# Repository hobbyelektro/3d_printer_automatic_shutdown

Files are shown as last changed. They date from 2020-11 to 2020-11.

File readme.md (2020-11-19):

# Automatic 3D printer shutdown



Documentation
--------------------
https://www.hobbyelektro.eu/automaticke-vypnuti-3d-tiskarny/

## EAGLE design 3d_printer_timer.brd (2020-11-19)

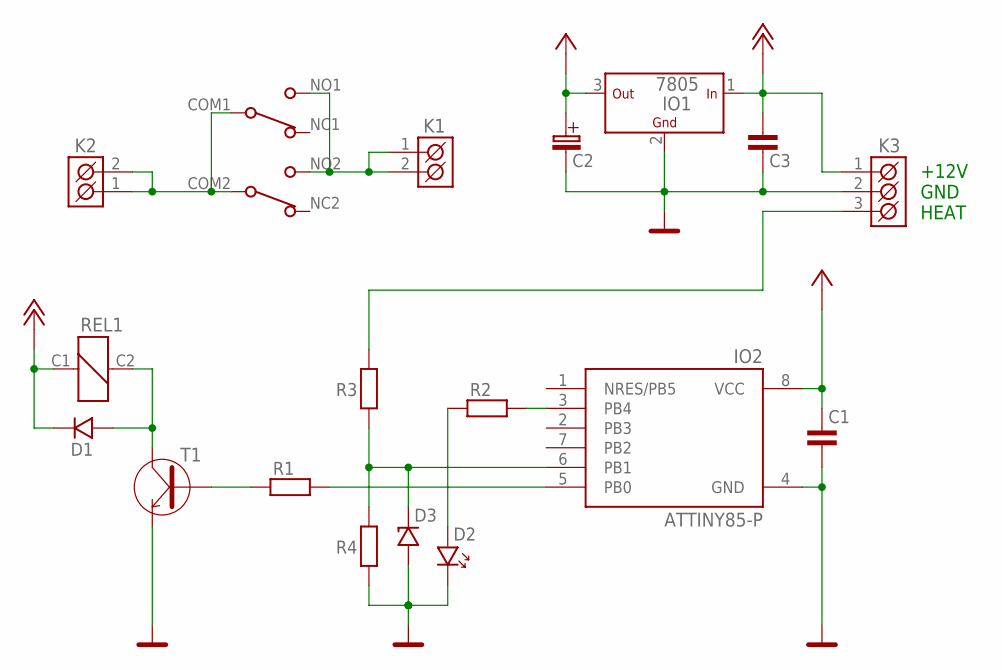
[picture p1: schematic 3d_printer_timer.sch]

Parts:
C1, C3: 100n; 1206
C2: 100u; C-EL_2,5
D1: 1N4148; DO35
D2: LED_3
D3: 5V1; DO35
IO1: 7805; TO-220S
IO2: ATTINY85-P; PDIP08_300MIL
K1, K2: ARK500/2
K3: ARK500/3
R1: 1k; R-10
R2: 330R; R-10
R3, R4: R_10; R-10
REL1: 40.52; RELEMZPA92
T1: BC546; TO-92

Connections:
+5V: C1.2, C2.C+ (C_EL+), IO1.3 (OUT), IO2.8 (VCC)
+12V: C3.2, D1.K, IO1.1 (IN), K3.1 (K1), REL1.C1
GND: C1.1, C2.C- (C_EL-), C3.1, D2.K, D3.A, IO1.2 (GND), IO2.4 (GND), K3.2 (K2), R4.1, T1.3 (E)
unnamed: K2.1 (K1), K2.2 (K2), REL1.COM1 (COM), REL1.COM2 (COM)
unnamed: K1.1 (K1), K1.2 (K2), REL1.NO1 (NO), REL1.NO2 (NO)
unnamed: D1.A, REL1.C2, T1.1 (C)
unnamed: R1.1, T1.2 (B)
unnamed: IO2.5 (PB0), R1.2
unnamed: IO2.3 (PB4), R2.2
unnamed: D2.A, R2.1
unnamed: D3.K, IO2.6 (PB1), R3.1, R4.2
unnamed: K3.3 (K3), R3.2

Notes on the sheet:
+12V GND HEAT

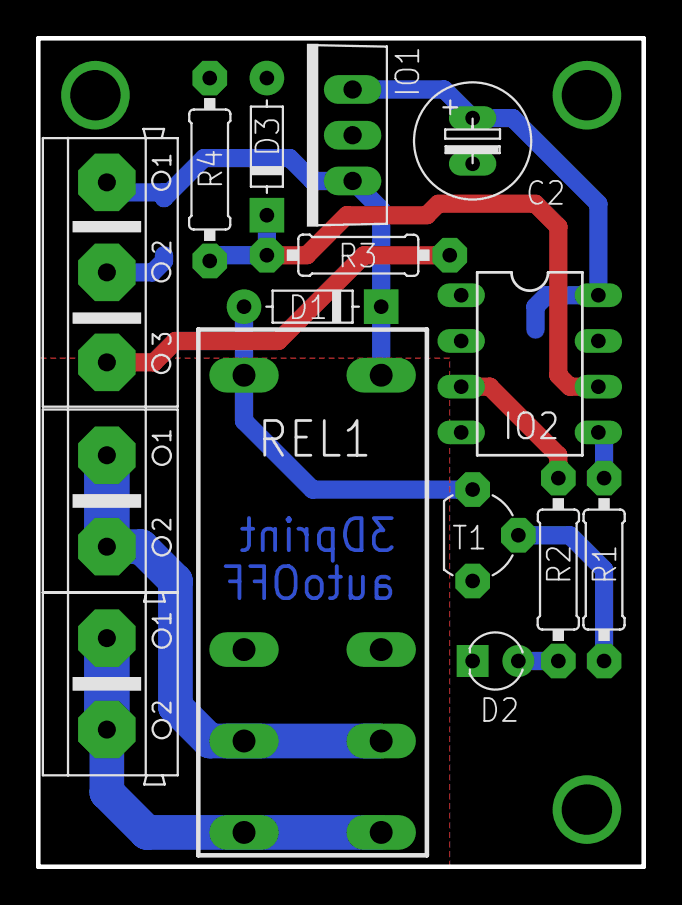
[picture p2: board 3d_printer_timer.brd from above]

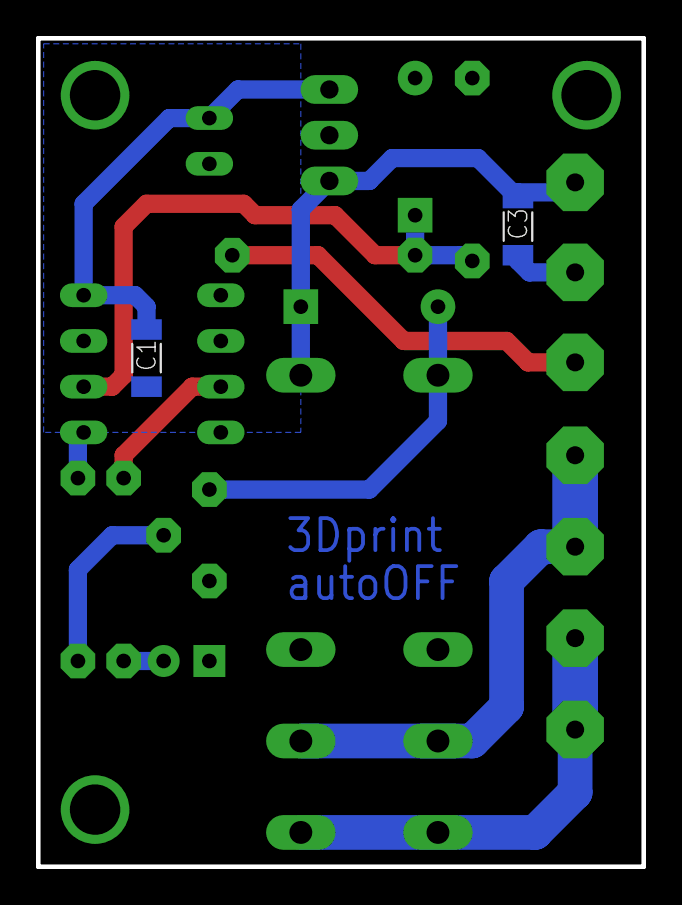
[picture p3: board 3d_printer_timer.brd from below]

Board: 2 copper layers, 33.6 x 46.0 mm, 17 parts (2 on the bottom side), 12 nets.

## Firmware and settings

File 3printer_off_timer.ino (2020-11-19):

const int input = 1;
const int output = 0;
const int led = 4;
long sekunda = 999;
int timeout = 300;
unsigned long aktualniMillis = 0;
unsigned long minulyMillis = 0;
unsigned long aktualniLedMillis = 0;
unsigned long minulyLedMillis = 0;
int aktualniCas = 0;
int inputState = 0;
int relayState = 1;
int ledState = 1;
int minulyState = 0;

void setup() {
  pinMode(input, INPUT);
  pinMode(output, OUTPUT);
  pinMode(led, OUTPUT);}

void loop() {
  aktualniMillis = millis();
  if((aktualniMillis - minulyMillis) > sekunda){
    minulyMillis = aktualniMillis;
    aktualniCas = aktualniCas + 1;} 
  inputState = digitalRead(input);
  if((inputState != minulyState) && (relayState == 1)){
    aktualniCas = 0;}
  minulyState = inputState;

  if(aktualniCas > timeout){
    relayState = LOW;}
  else {
    relayState = HIGH;}
  
  if((aktualniCas > 10) && (aktualniCas < timeout)){
    aktualniLedMillis = millis();
  if(aktualniLedMillis - minulyLedMillis > 500){
    minulyLedMillis = aktualniLedMillis;
    if(ledState == LOW){
      ledState = HIGH;}
    else {
      ledState = LOW;}
   }
  }
  else if(aktualniCas > timeout){
    ledState = LOW;}
  else {
    ledState = HIGH;}
    
  digitalWrite(output, relayState);
  digitalWrite(led, ledState);
}

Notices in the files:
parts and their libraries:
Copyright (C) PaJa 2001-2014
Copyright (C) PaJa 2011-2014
